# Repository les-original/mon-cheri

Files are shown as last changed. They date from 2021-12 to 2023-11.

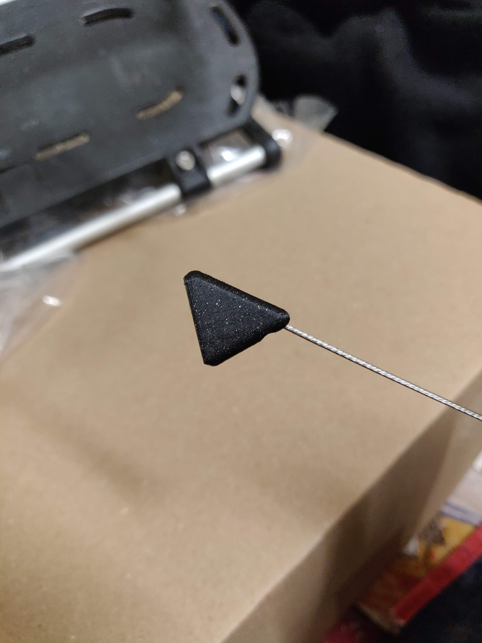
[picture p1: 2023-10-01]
images/IMG_20211228_134208.jpg

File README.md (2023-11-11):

# **mon-cheri**
## Printable crimps braided cable simps.
`mon-cheri` are open-source, printed crimps to keep bicycle brake and shifter cable ends from fraying. They look neat, are easy to grip and removable for maintenaince. 

## Two screw sizes, one cable size, many shapes
`mon-cheri` comes in a few shapes.
- **tri** - a triangle
- **ball** - a small round
- **barrel** - a puck-shaped
- **square** - `coming soon`
- **heart** - `coming soon`

Each shape is provided in M3 and M4 sizes. 

M3 allows some shapes be a bit smaller (lighter!) but the threads are delicate, and the hex wrench size is *rare*.

M4 is a more common hex wrench size to carry, and makes everythin a bit more robust.

Every `mon-cheri` should fit typical brake and shifter cables of all sorts.

### Recommended grub screw lengths

| Style  | tri | ball | barrel |
|---|---|---|---|
| **M3** | 4 mm | 5 mm | 5 mm |
| **M4** | 5 - 6 mm | 3.5-4 mm | 3.5-4 mm |

## Instructions
1. You'll need a short grub (headless) screw
1. Print in a tough, outdoor-friendly filament like PETG
   1. Use at least 2 perimeters. They're so small infill doesn't make much of a difference.
1. Use a poker to bore out the cable hole to clear any stringing
1. Thread in the grub screw - keep it straight!
1. Place it on the end of a cleanly cut cable
1. Tighten down to a reasonable tension - *not too tight!*
1. Ride your bike!
1. Next time you need to remove the cables or make adjustments, just loosen up and repeat. 

## Source files
This project is created using FreeCAD -  a free and open source program. Design source files are available and accessible in this repository.

You can make adjustments to most parameters that drive the model, and so long as they're reasonable it should not break! This can be useful if your grub screws are a tight or loose fit, or if you'd like to create a larger size.

If you think your contribution would benefit others, feel free to open a pull request.

Suggestions or some troubles? Please open a new issue in this repository.

---
An open source product from the good people at [Les Original](https://www.lesoriginal.com)

Say thanks on Instagram [@lesoriginal](https://www.instagram.com/lesoriginal)

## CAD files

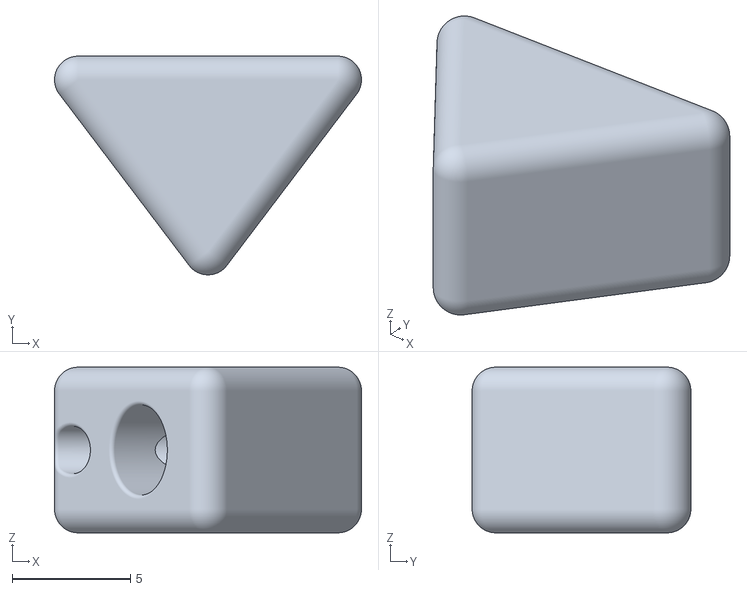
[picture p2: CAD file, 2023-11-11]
mon-cheri-tri-m4.stl
13.0 x 9.24 x 7.00

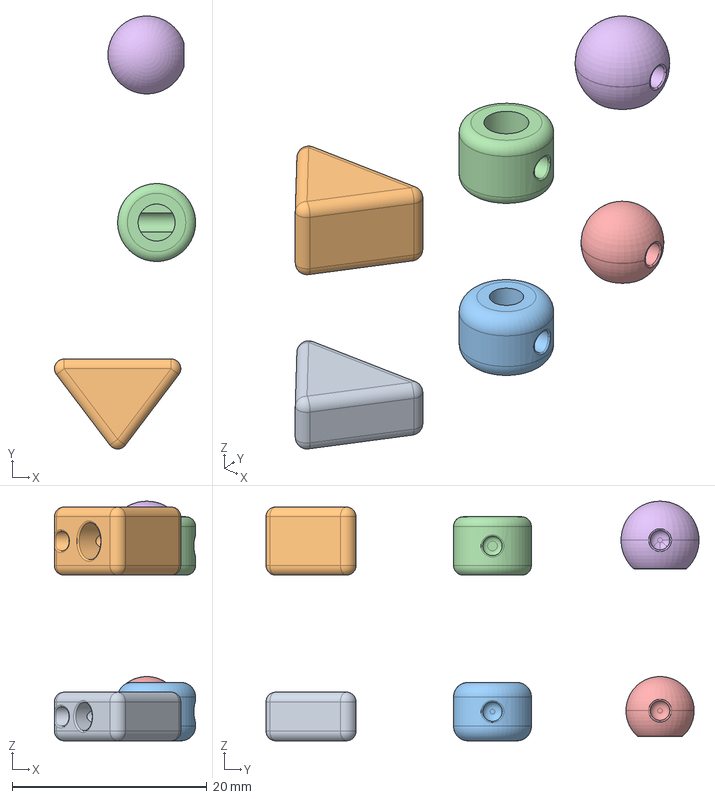
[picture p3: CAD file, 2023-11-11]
src/mon-cheri.FCStd
14.5 x 44.4 x 24.6 mm
tri-m3
tri-m4
barrel-m3
barrel-m4
ball-m3
ball-m4

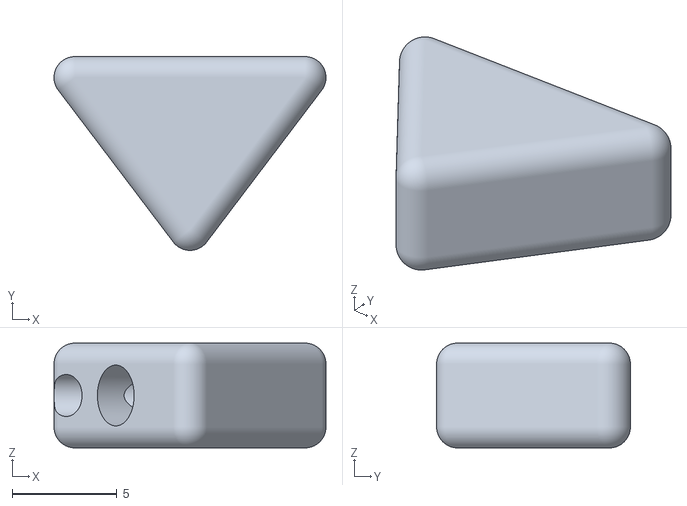
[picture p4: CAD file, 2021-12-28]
mon-cheri-tri-m3.stl
13.0 x 9.24 x 5.00

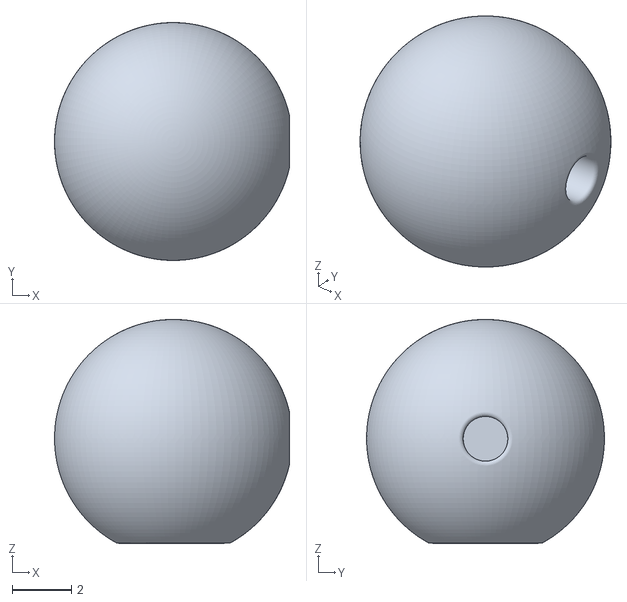
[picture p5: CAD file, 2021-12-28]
mon-cheri-ball.stl
7.90 x 8.00 x 7.54

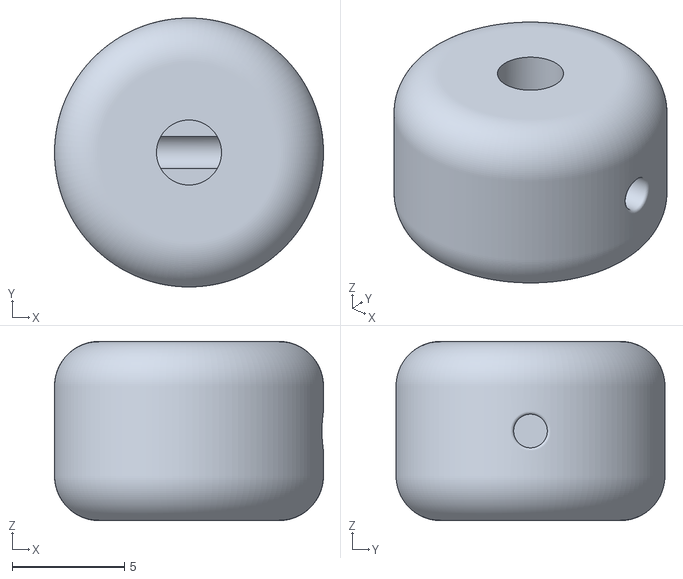
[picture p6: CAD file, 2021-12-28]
mon-cheri-Barrel.stl
12.0 x 12.0 x 8.00

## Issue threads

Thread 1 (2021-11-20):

Cable crimp for brakes & shifters

marcsist, 2021-11-20:
A 3D printed bead or ball with a feed-in for cable, and a grub screw to set it in place, like the well known 'bike cherry'.

- [x] #2
- [x] #3
- [x] Drum shaped cable crimp
- [x] Ball shaped cable crimp
- [x] Triangle shaped cable crimp

Closed 2021-12-28.

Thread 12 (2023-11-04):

❤️ Heart shape mon-cheri

marcsist, 2023-11-04:
# A heart-shaped mon-cheri for bike lovers
Ideally I can get this out in time for valentines day - would look just right in red.

- [ ] Decide on orientation
- [ ] Model it up
- [ ] Test print
- [ ] Release

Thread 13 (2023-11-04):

Visible artefacts from screw hole on tri

marcsist, 2023-11-04:
When printed at a lovely .24 layer height the thin walls of the screw hole on tri-m4 pull in a bit, creating a visible artefact.

- [ ] increase wall thicknesses
- [ ] test print in shiny black filament

Closed 2023-11-11.

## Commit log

2021-12-23 started mon-cheri model
    Basic scaffolding for the models. In a single file, based on #2 and #3 ... 3 models will live in this base file.
    [mon-cheri.FCStd]
2021-12-23 Added holes to tri
    [mon-cheri.FCStd]
2021-12-28 added 3 stl files
    First printable alpha release!
    [mon-cheri-Barrel.stl, mon-cheri-ball.stl, mon-cheri-tri.stl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]
2021-12-28 Smaller wbut ith bigger holes!
    After some first testing, I decided to bore out the hole to fit bigger cables and frays. The models have all been updated to be a bit smaller, faster to print, and use less material.
    [mon-cheri-tri.stl, mon-cheri.FCStd]
2022-01-01 Renamed operations
    [mon-cheri.FCStd]
2023-10-01 Welcome back
    Checking in, not sure what's changed!
    [WIP-mon-cheri-rounds.3mf, mon-cheri.FCStd, print-settings_mon-cheri-tri.3mf]
2023-10-02 Update tri model and spreadsheet
    [mon-cheri.FCStd]
2023-10-02 Beefing things up
    Making everything a wee bit bigger to fit the big bolts
    [mon-cheri.FCStd]
2023-10-02 Created STL for M4
    [mon-cheri-tri-m4.stl]
2023-10-02 Hole test passed
    [mon-cheri-tri-m4.stl, mon-cheri.FCStd, print-settings_mon-cheri-tri-m4.3mf]
2023-10-03 Adjusting tri-m4 for clearance
    Bigger BoltHoleM4 cuts it a bit close with the cable hole, so adding an offset and additional depth to compensate
    [mon-cheri.FCStd]
2023-10-03 Improved ball printability
    ball had a hard time sticking to the bed, so I've increased the chamfer. Bon chance!
    [mon-cheri-tri-m4.stl, mon-cheri.FCStd]
2023-10-03 Updated naming
    [mon-cheri-tri-m3.stl]
2023-10-11 Reduced BoltHole by 0.1mm
    Improved threading for finer grub screws
    [mon-cheri-tri-m4.stl, mon-cheri.FCStd]
2023-10-11 Added recommended bolt sizes to spreadsheet
    [mon-cheri.FCStd]
2023-11-05 Added 1mm width to mon-cheri/tri-m4
    [20x-mon-cheri-tri-m4.3mf, PETG-20x-mon-cheri-ball-m4.3mf, mon-cheri.FCStd]
2023-11-05 7mm wide tri-m4
    [mon-cheri-tri-m4.stl]
2023-11-11 Added small filet to holes on tri
    To eliminate the artifact a small filet was added to the holes. It' hardly noticable but seems to resolve the blip.
    ## Changes
    - set the width of tri-m4 to 7mm
    - added a tiny (0.17mm) radius to the holes on the tri
    ## Other
    - Renaming
    [mon-cheri-tri-m4.stl, mon-cheri.FCStd]
2023-11-11 Repo and docs cleanup
    In this merge I've removed some old files, move the source into the src folder and updated the README.
    I've removed the Production folder and files. New print files can be added in the future.
    [20x-mon-cheri-tri-m4.3mf, PETG-20x-mon-cheri-ball-m4.3mf, WIP-mon-cheri-rounds.3mf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]
2026-10-29 Add heart and square cable crimps (#17)
    * Add a heart-shaped cable crimp
    A point-down heart in M3 and M4. The cable enters at the bottom
    point and stops inside the body, and the grub screw comes through
    the front and pinches the cable.
    * Smooth the radius where the heart's holes meet the face.
    The round beside the cable hole had been cut and patched, which left flat steps. The cable lip and the screw mouth are now a clean radius on both the M3 and M4 hearts. The pinch is unchanged, and the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
2026-11-02 Add Tier A shapes: hex, bean, drop, squircle (#19)
    * Add Tier A cable crimps: hex, bean, drop, and squircle.
    Each shape ships in M3 and M4 with the same cable bore, grub holes, 1 mm outside fillet, and hole lip blends as the existing family. Square-style pinch for hex, drop, and squircle; barrel-style pinch for the bean oval.
    * Fix Tier A hex, drop, and squircle cable geometry
    Rebuild side holes using square-style placement (0.175 mm mouth inset,
    outer lip on the true mouth circle), correct hex flat-to-flat orientation,
    slice-based drop mouth after fillet, and squircle holes before 8° tilt.
    Add mesh topology checks; keep bean on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
